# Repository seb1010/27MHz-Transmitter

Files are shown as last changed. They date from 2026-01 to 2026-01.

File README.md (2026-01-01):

# 27MHz-Transmitter
27.12MHz wiresless transmitter

## Basic flow
* There is a external oscillator that wakes up the MCU a few times every second (allowing MCU to sleep 99.9% of the time) if this is the Nth time the MCU has been woken up it sends a packet
* The MCU powers up the RF chain
* The MCU reads from the sensors then puts this information into a packet
* This packet has ECC added with 255, 154 BCH code. There is an additional framing section added that is not protected by error correction
* The packet is sent out by toggling a gpio pin with 20us bit period
* This waveform is pulse shapped by low pass filters before being sent to the modulator
* The modulated waveform is sent out over the airwaves
* The MCU powers off the board and goes back to sleep

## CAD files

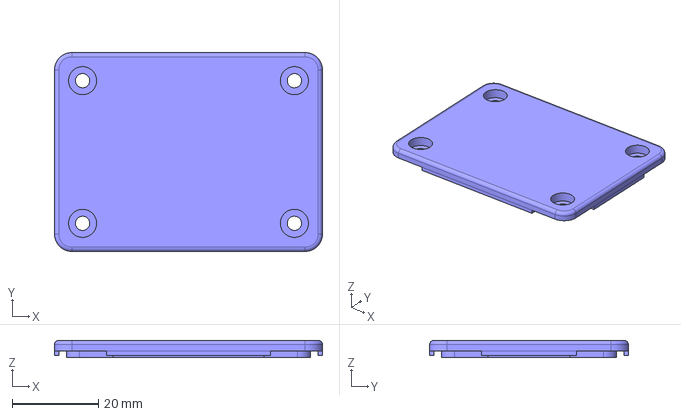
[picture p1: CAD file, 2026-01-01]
enclosure/27m_tx_sensor-lid_v2.step
62.0 x 46.0 x 4.00 mm

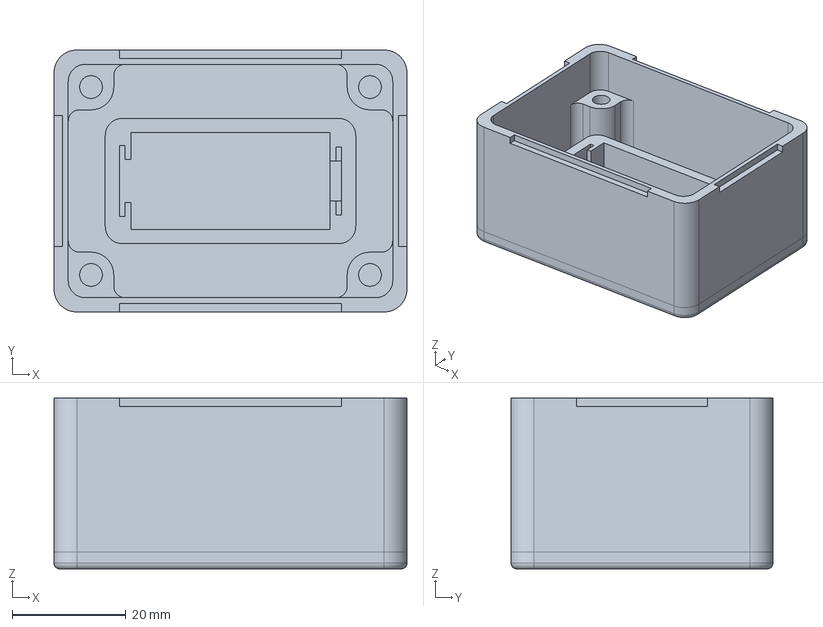
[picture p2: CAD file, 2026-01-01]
enclosure/27m_tx_sensor-Body_v2.step
62.0 x 46.0 x 30.0 mm

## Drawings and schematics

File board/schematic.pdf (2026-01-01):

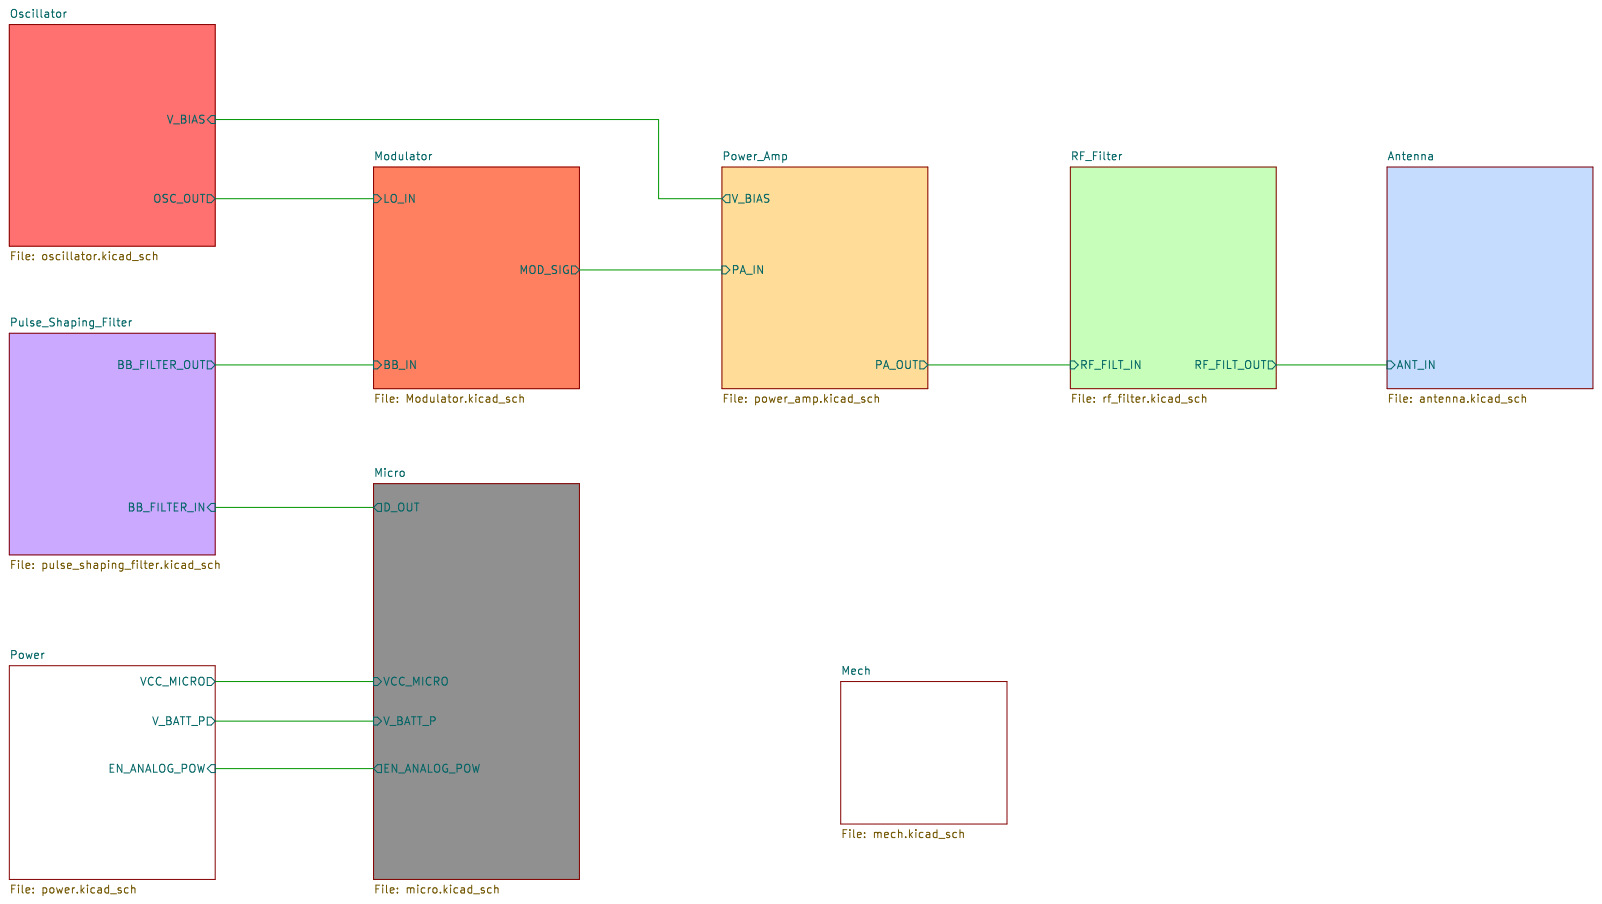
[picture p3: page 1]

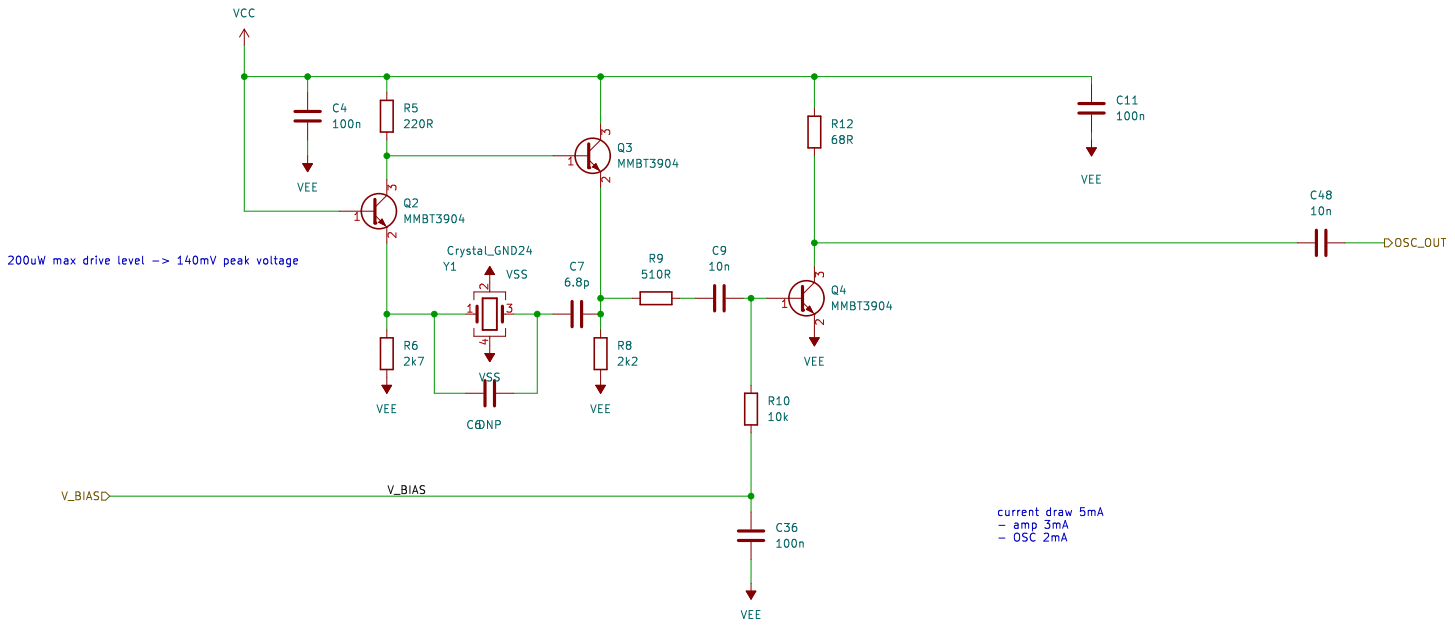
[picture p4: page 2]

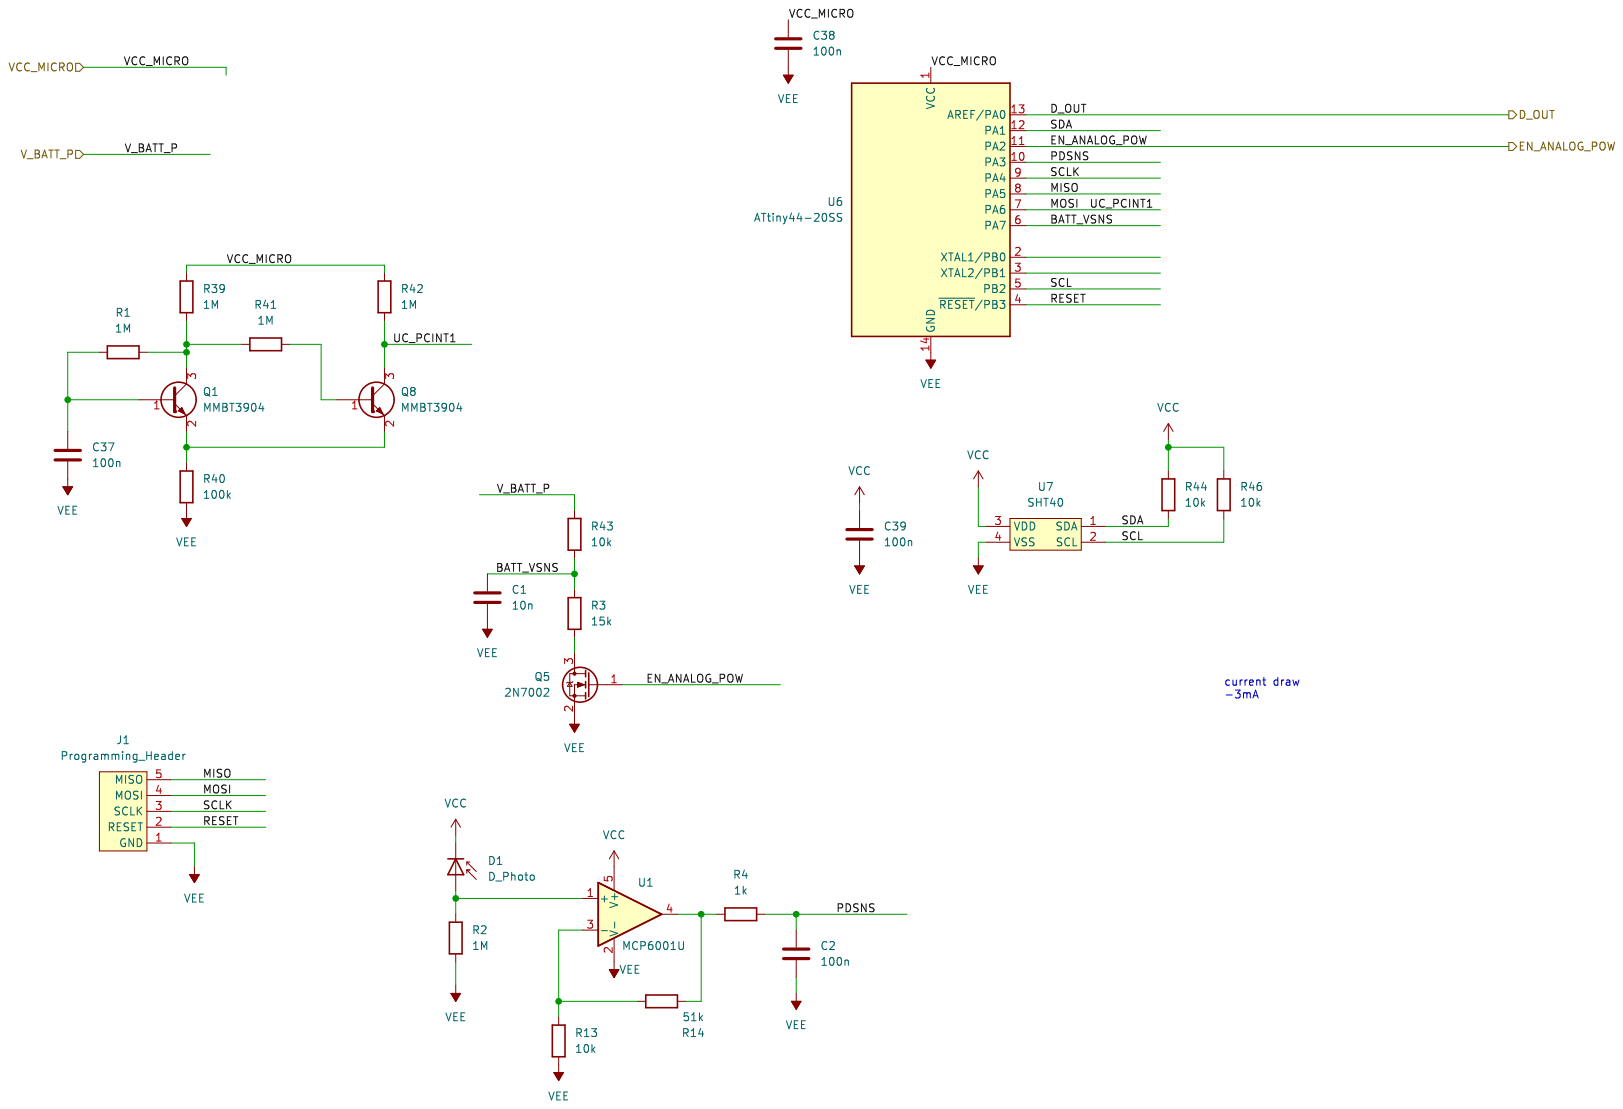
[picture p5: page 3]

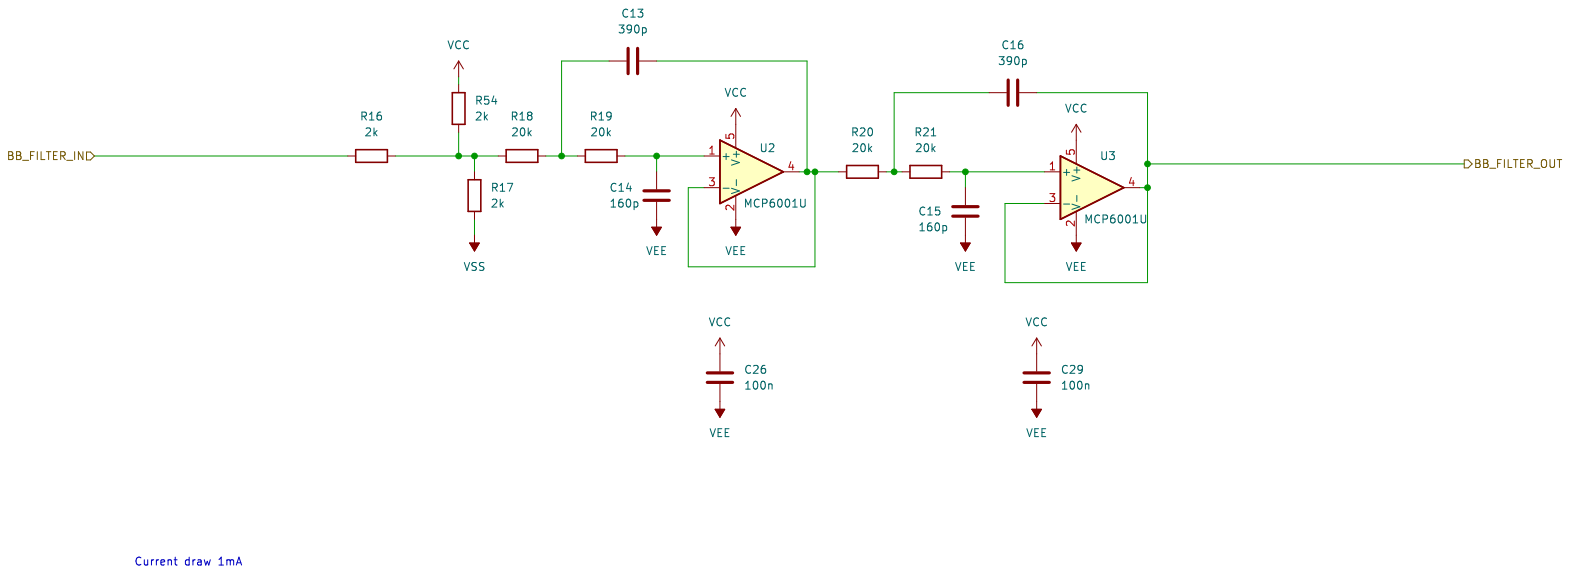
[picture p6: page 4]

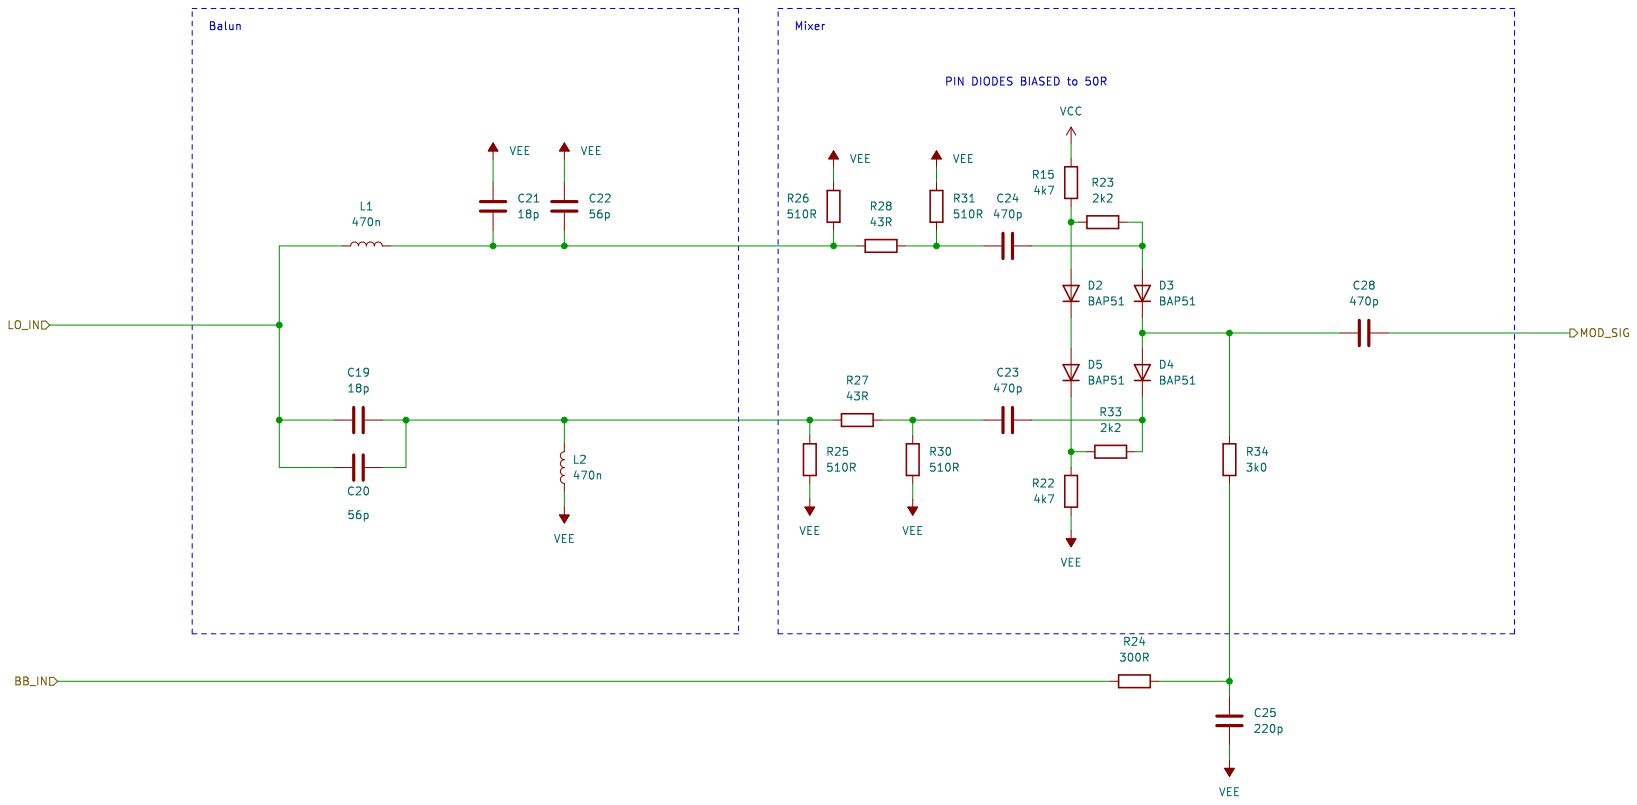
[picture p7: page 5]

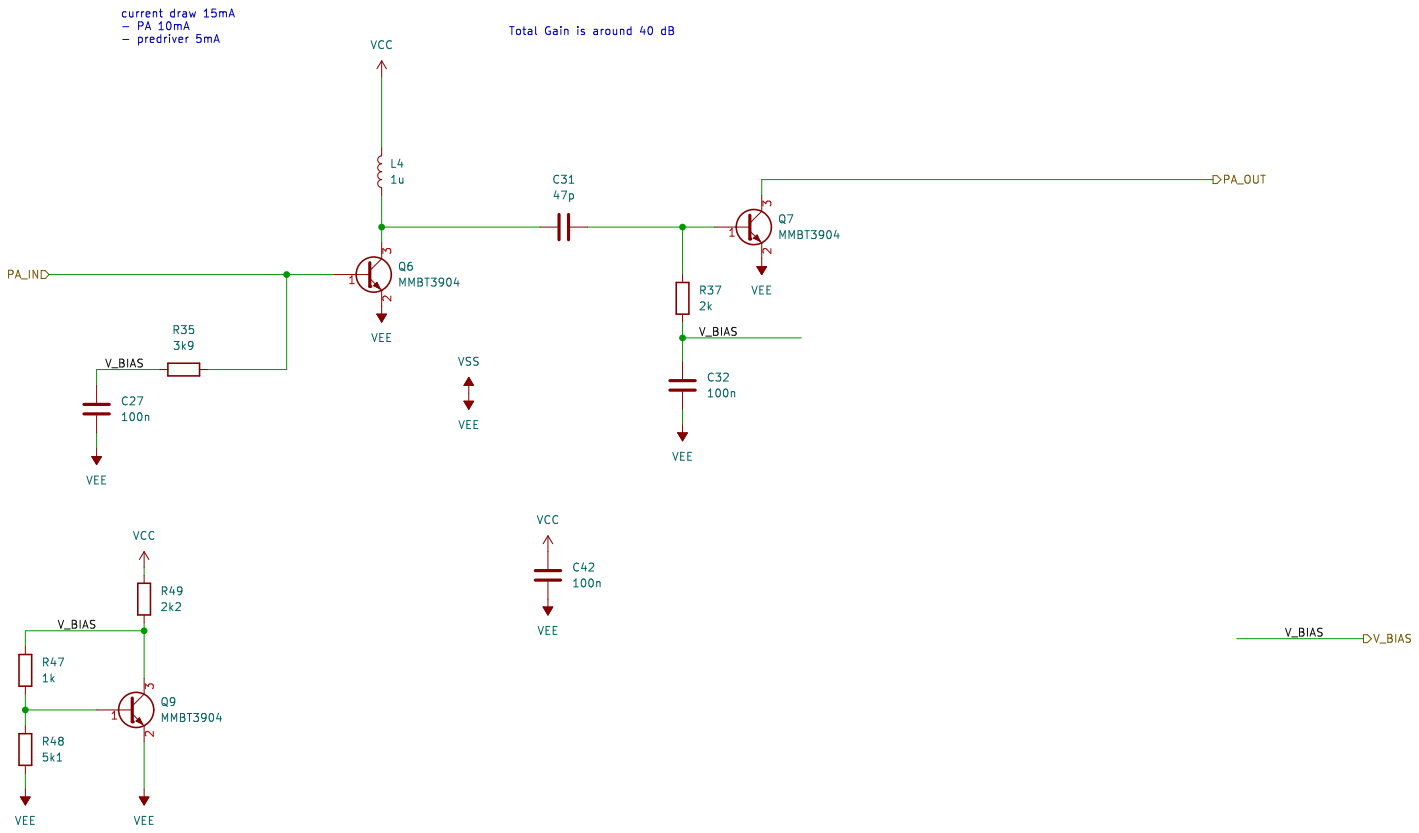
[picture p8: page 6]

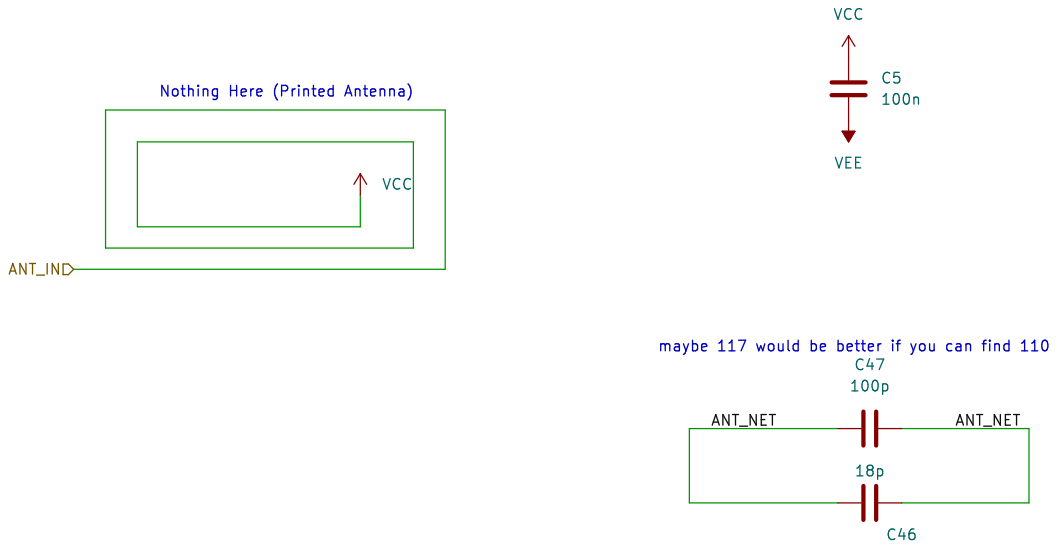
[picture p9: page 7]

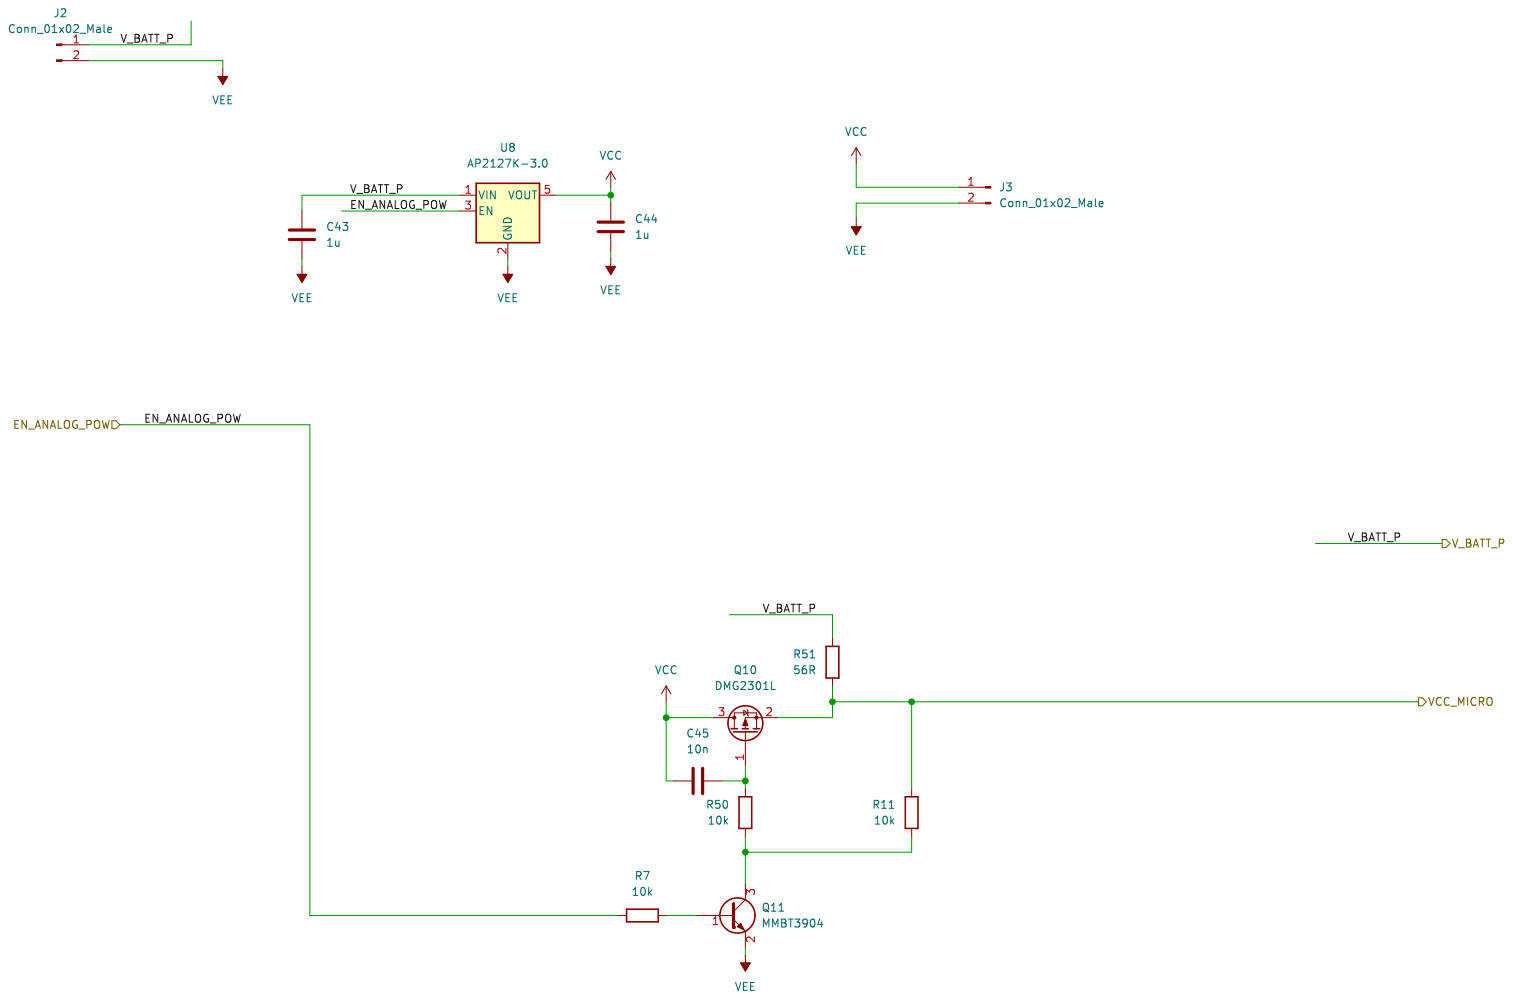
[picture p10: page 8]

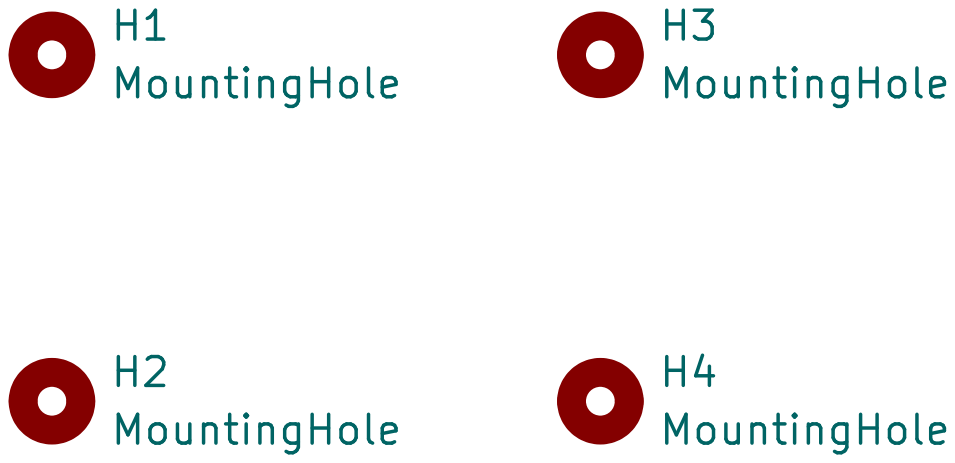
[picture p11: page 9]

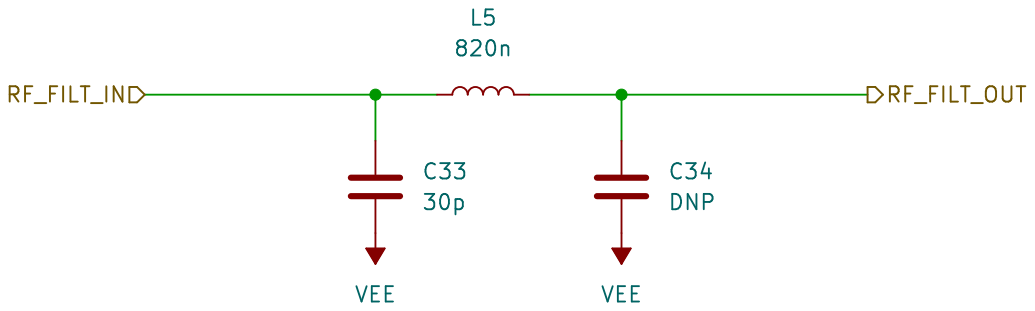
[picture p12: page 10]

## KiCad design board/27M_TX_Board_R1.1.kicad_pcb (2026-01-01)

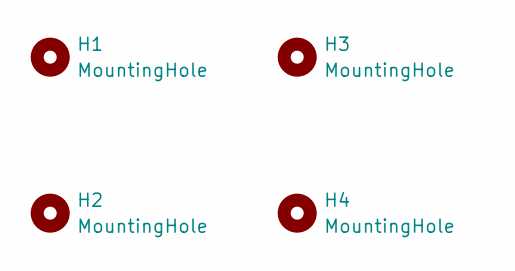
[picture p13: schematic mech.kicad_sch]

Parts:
H1, H2, H3, H4: MountingHole; m3_hole_no_copper

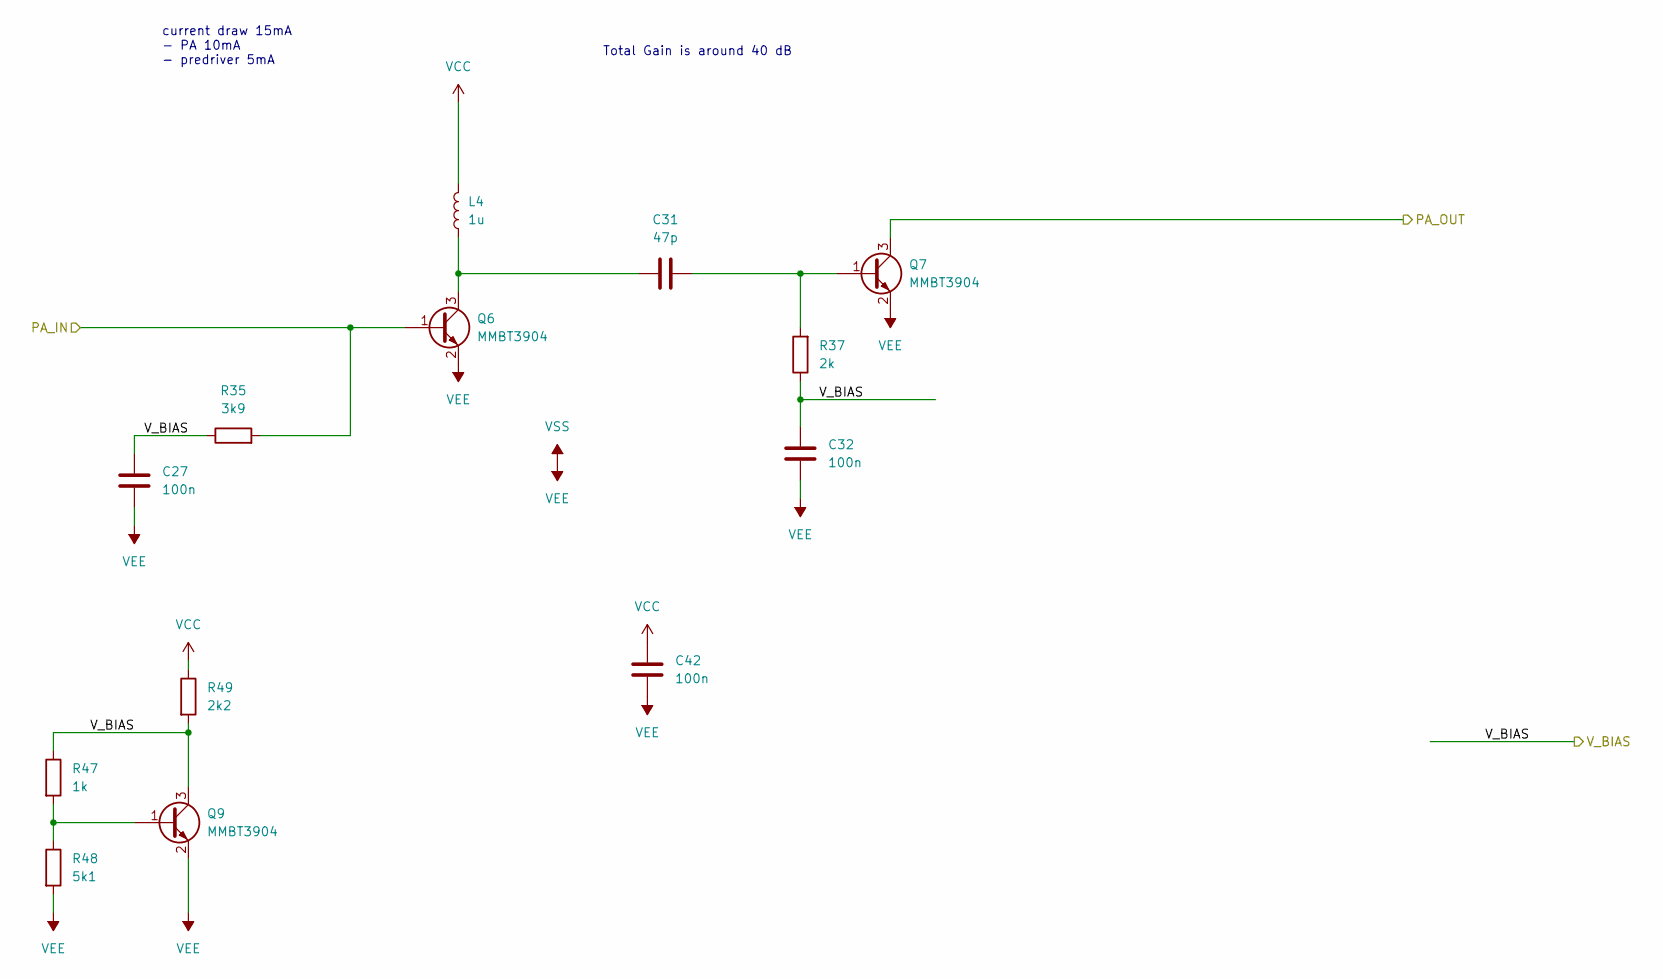
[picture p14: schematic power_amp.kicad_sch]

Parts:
C27, C32, C42: 100n; C_0603_1608Metric
C31: 47p; C_0603_1608Metric
L4: 1u; C_0805_2012Metric
Q6, Q7, Q9: MMBT3904; SOT-23
R35: 3k9; C_0603_1608Metric
R37: 2k; C_0603_1608Metric
R47: 1k; C_0603_1608Metric
R48: 5k1; C_0603_1608Metric
R49: 2k2; C_0603_1608Metric

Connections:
/Modulator/MOD_SIG: Q6.1 (B), R35.2; also elsewhere on the board
/Oscillator/V_BIAS: C27.1, C32.1, Q9.3 (C), R35.1, R37.1, R47.1, R49.2; also elsewhere on the board
/Power_Amp/PA_OUT: Q7.3 (C); also elsewhere on the board
unnamed: C31.1, L4.1, Q6.3 (C)
unnamed: C31.2, Q7.1 (B), R37.2
unnamed: Q9.1 (B), R47.2, R48.1
VCC: C42.1, L4.2, R49.1; also elsewhere on the board
VEE: C27.2, C32.2, C42.2, Q6.2 (E), Q7.2 (E), Q9.2 (E), R48.2; also elsewhere on the board

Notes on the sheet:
current draw 15mA - PA 10mA - predriver 5mA
Total Gain is around 40 dB

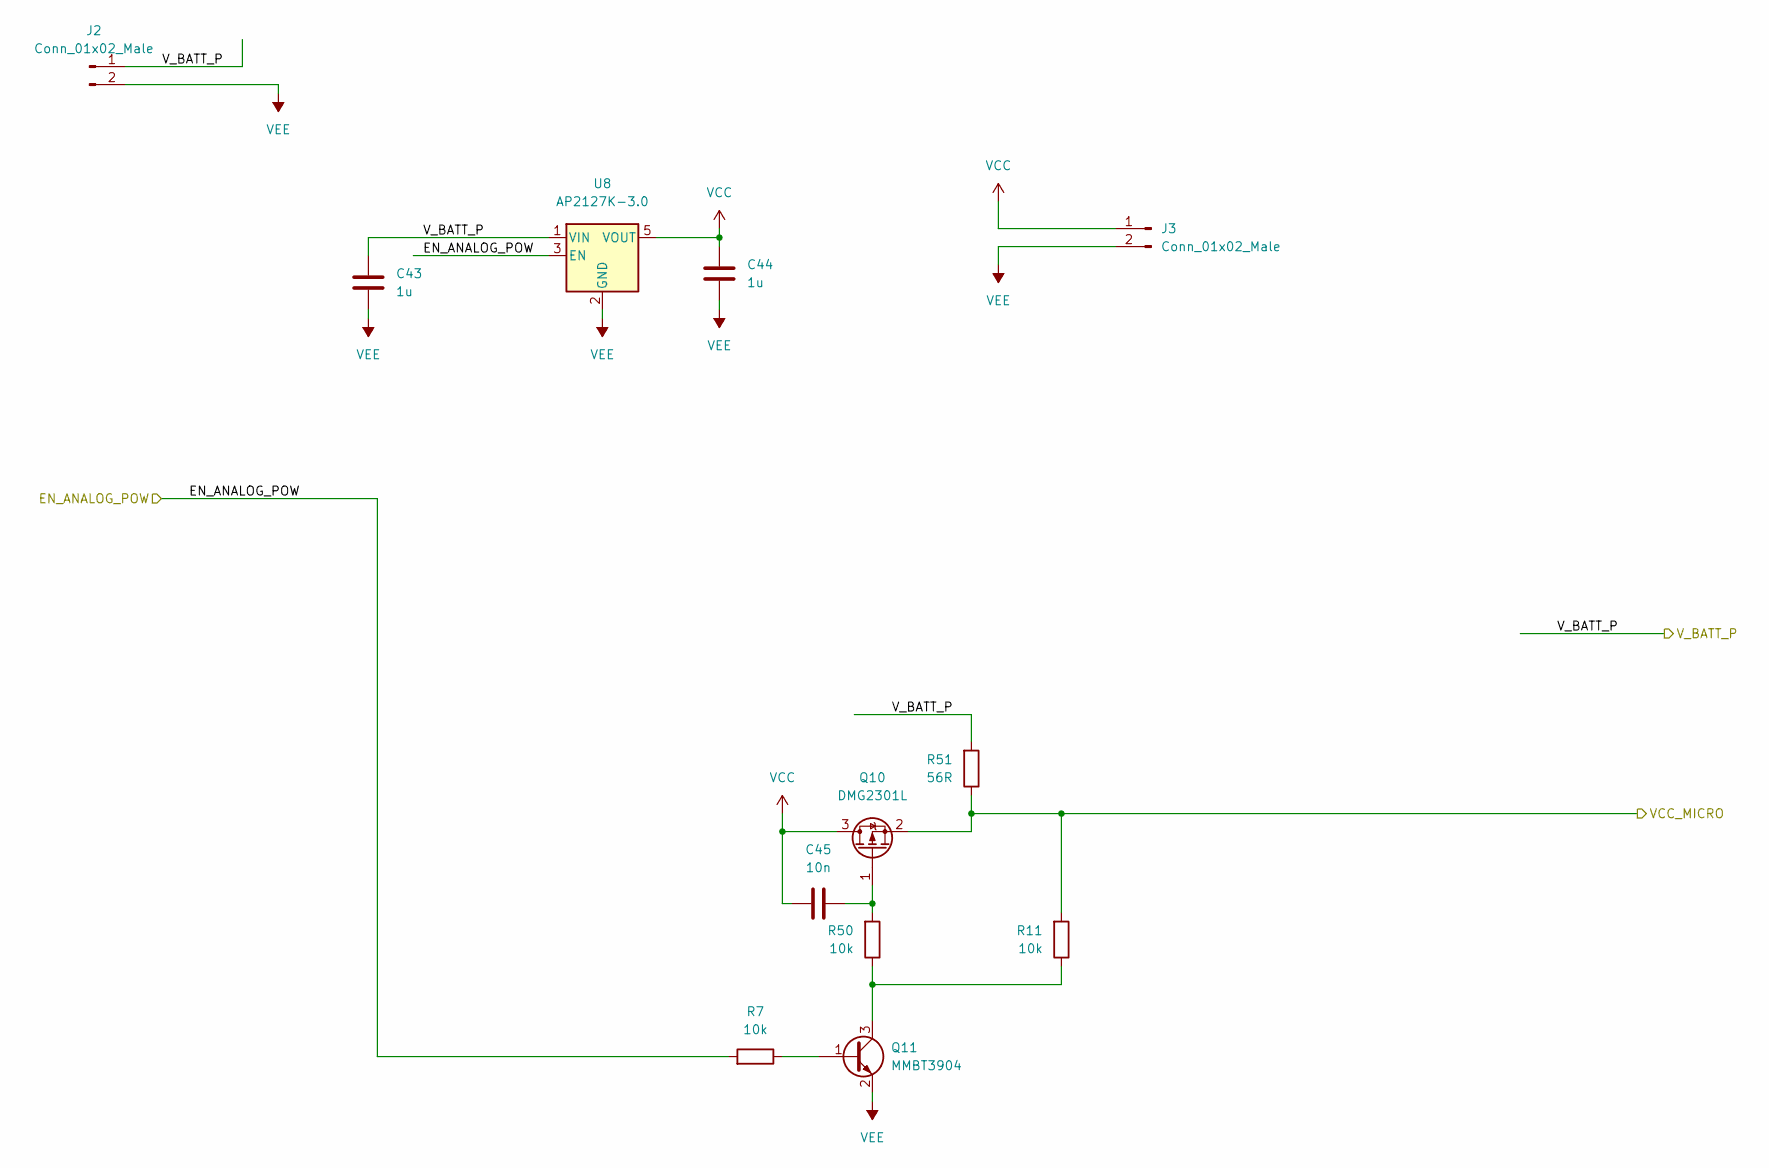
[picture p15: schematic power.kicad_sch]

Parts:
C43, C44: 1u; C_0603_1608Metric
C45: 10n; C_0603_1608Metric
J2, J3: Conn_01x02_Male; JST-ZH-2
Q10: DMG2301L; SOT-23
Q11: MMBT3904; SOT-23
R7, R11, R50: 10k; C_0603_1608Metric
R51: 56R; C_0603_1608Metric
U8: AP2127K-3.0; SOT-23-5

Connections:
/Micro/EN_ANALOG_POW: R7.2, U8.3 (EN); also elsewhere on the board
/Micro/VCC_MICRO: Q10.2 (S), R11.2, R51.1; also elsewhere on the board
/Micro/V_BATT_P: C43.1, J2.1, R51.2, U8.1 (VIN); also elsewhere on the board
unnamed: C45.2, Q10.1 (G), R50.2
unnamed: Q11.1 (B), R7.1
unnamed: Q11.3 (C), R11.1, R50.1
VCC: C44.1, C45.1, J3.1, Q10.3 (D), U8.5 (VOUT); also elsewhere on the board
VEE: C43.2, C44.2, J2.2, J3.2, Q11.2 (E), U8.2 (GND); also elsewhere on the board

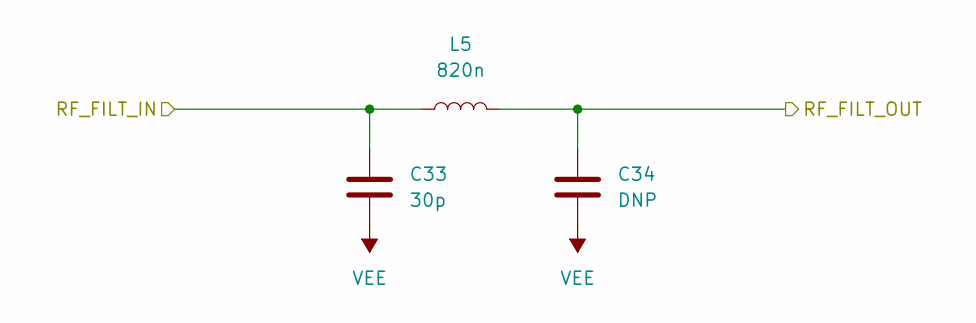
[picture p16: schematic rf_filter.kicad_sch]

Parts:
C33: 30p; C_0603_1608Metric
C34: DNP; C_0603_1608Metric
L5: 820n; C_0805_2012Metric

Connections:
/Power_Amp/PA_OUT: C33.1, L5.1; also elsewhere on the board
VCC: C34.1, L5.2; also elsewhere on the board
VEE: C33.2, C34.2; also elsewhere on the board

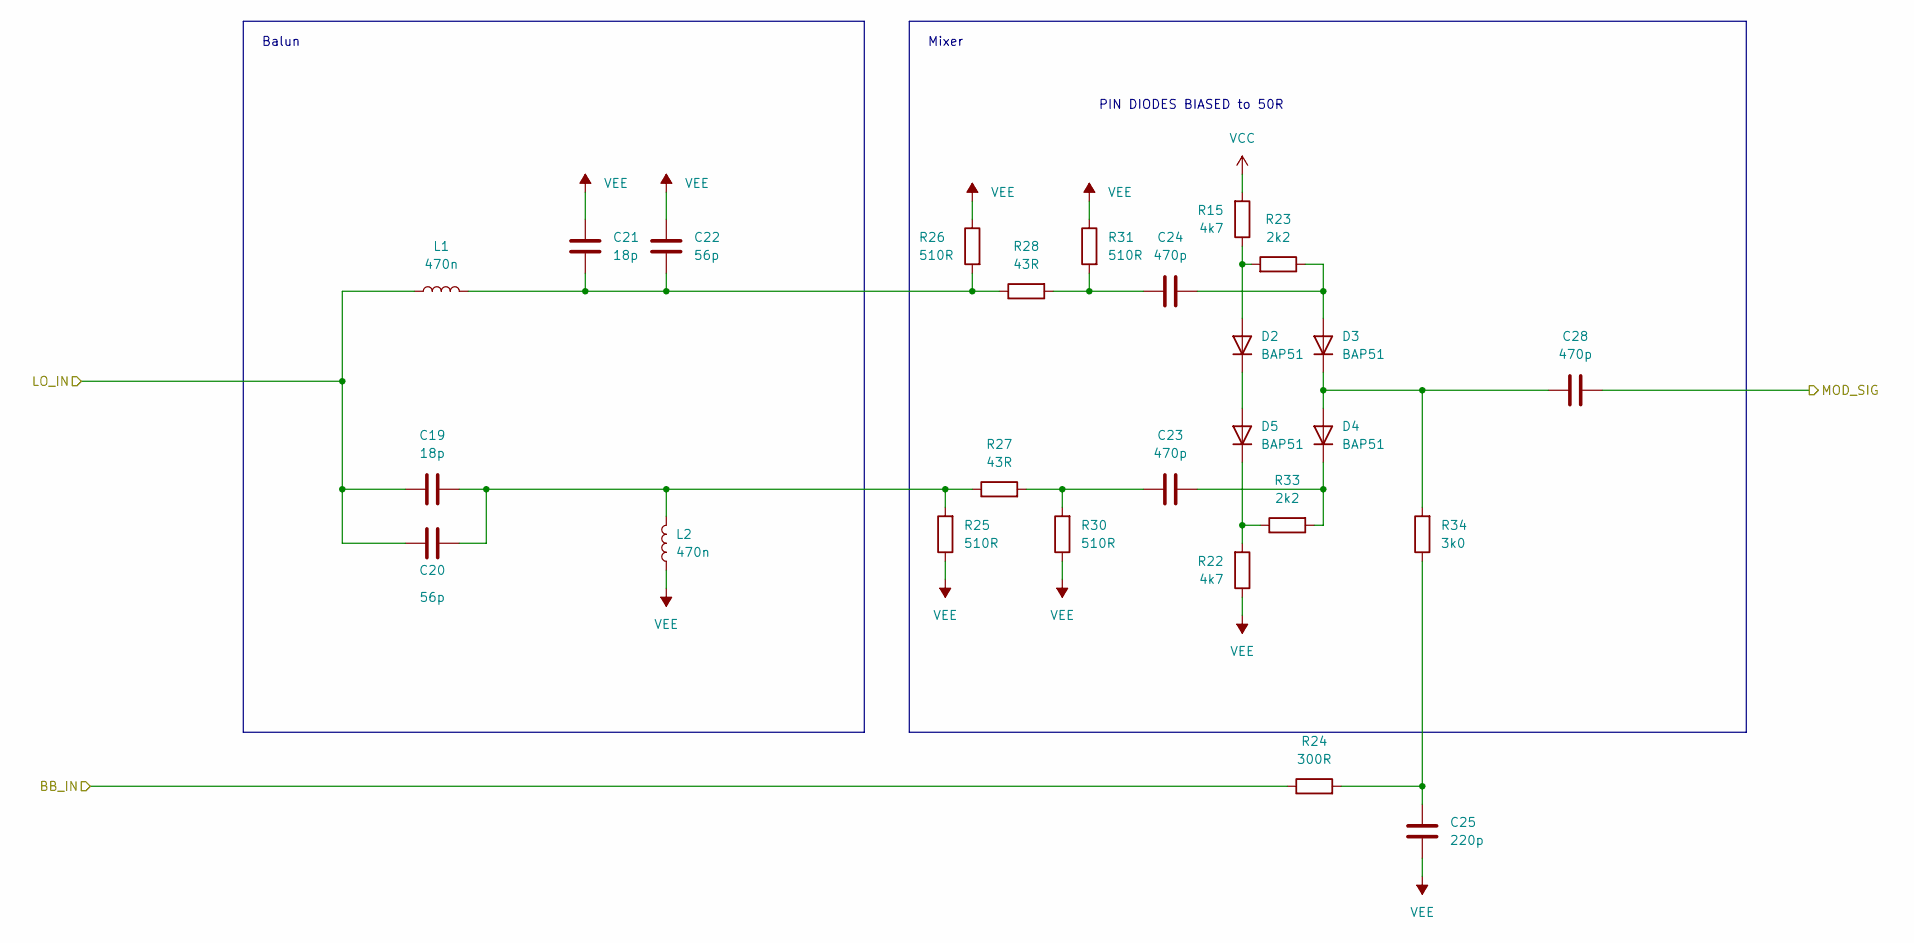
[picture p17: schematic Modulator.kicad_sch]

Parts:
C19, C21: 18p; C_0603_1608Metric
C20, C22: 56p; C_0603_1608Metric
C23, C24, C28: 470p; C_0603_1608Metric
C25: 220p; C_0603_1608Metric
D2, D3, D4, D5: BAP51; D_SOD-323
L1, L2: 470n; C_0805_2012Metric
R15, R22: 4k7; C_0603_1608Metric
R23, R33: 2k2; C_0603_1608Metric
R24: 300R; C_0603_1608Metric
R25, R26, R30, R31: 510R; C_0603_1608Metric
R27, R28: 43R; C_0603_1608Metric
R34: 3k0; C_0603_1608Metric

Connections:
/Modulator/BB_IN: R24.1; also elsewhere on the board
/Modulator/LO_IN: C19.1, C20.2, L1.1; also elsewhere on the board
/Modulator/MOD_SIG: C28.2; also elsewhere on the board
unnamed: C19.2, C20.1, L2.2, R25.2, R27.1
unnamed: C21.2, C22.2, L1.2, R26.2, R28.1
unnamed: C23.1, R27.2, R30.2
unnamed: C23.2, D4.1 (K), R33.2
unnamed: C24.1, R28.2, R31.2
unnamed: C24.2, D3.2 (A), R23.1
unnamed: C25.2, R24.2, R34.1
unnamed: C28.1, D3.1 (K), D4.2 (A), R34.2
unnamed: D2.1 (K), D5.2 (A)
unnamed: D2.2 (A), R15.1, R23.2
unnamed: D5.1 (K), R22.2, R33.1
VCC: R15.2; also elsewhere on the board
VEE: C21.1, C22.1, C25.1, L2.1, R22.1, R25.1, R26.1, R30.1, R31.1; also elsewhere on the board

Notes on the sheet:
Balun
Mixer
PIN DIODES BIASED to 50R

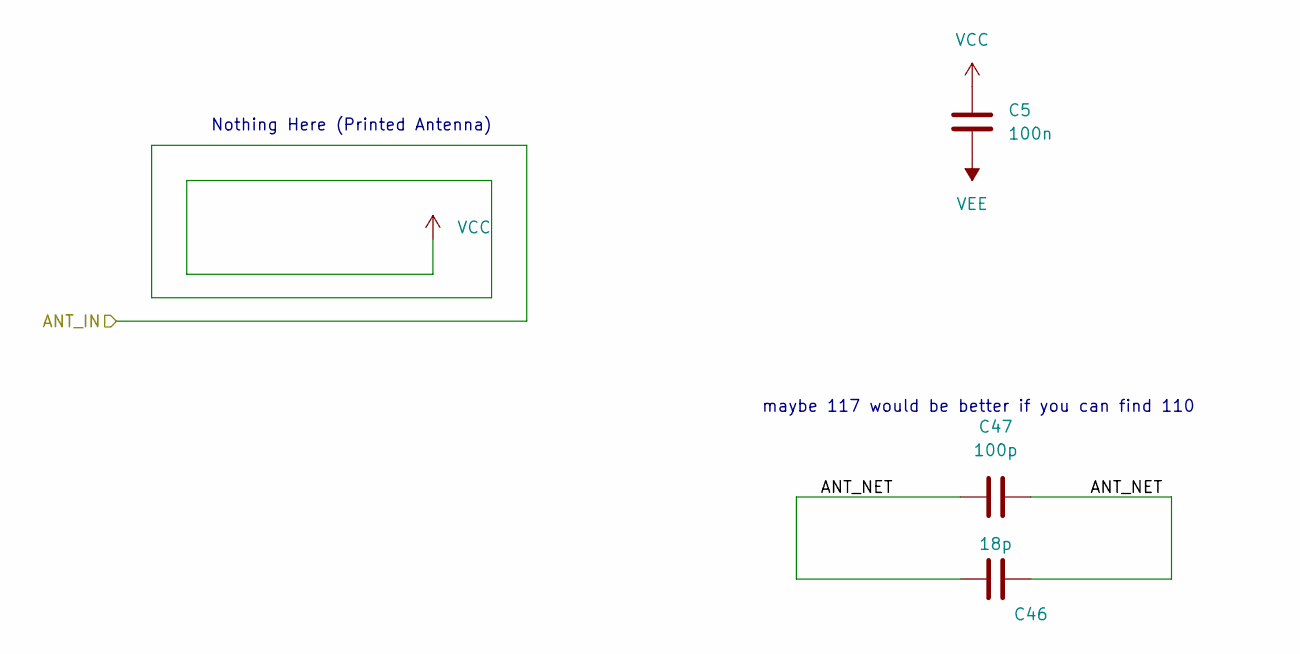
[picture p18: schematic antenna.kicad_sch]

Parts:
C5: 100n; C_0603_1608Metric
C46: 18p; C_0603_1608Metric
C47: 100p; C_0603_1608Metric

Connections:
/Antenna/ANT_NET: C46.1, C46.2, C47.1, C47.2
VCC: C5.1; also elsewhere on the board
VEE: C5.2; also elsewhere on the board

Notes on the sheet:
Nothing Here (Printed Antenna)
maybe 117 would be better if you can find 110

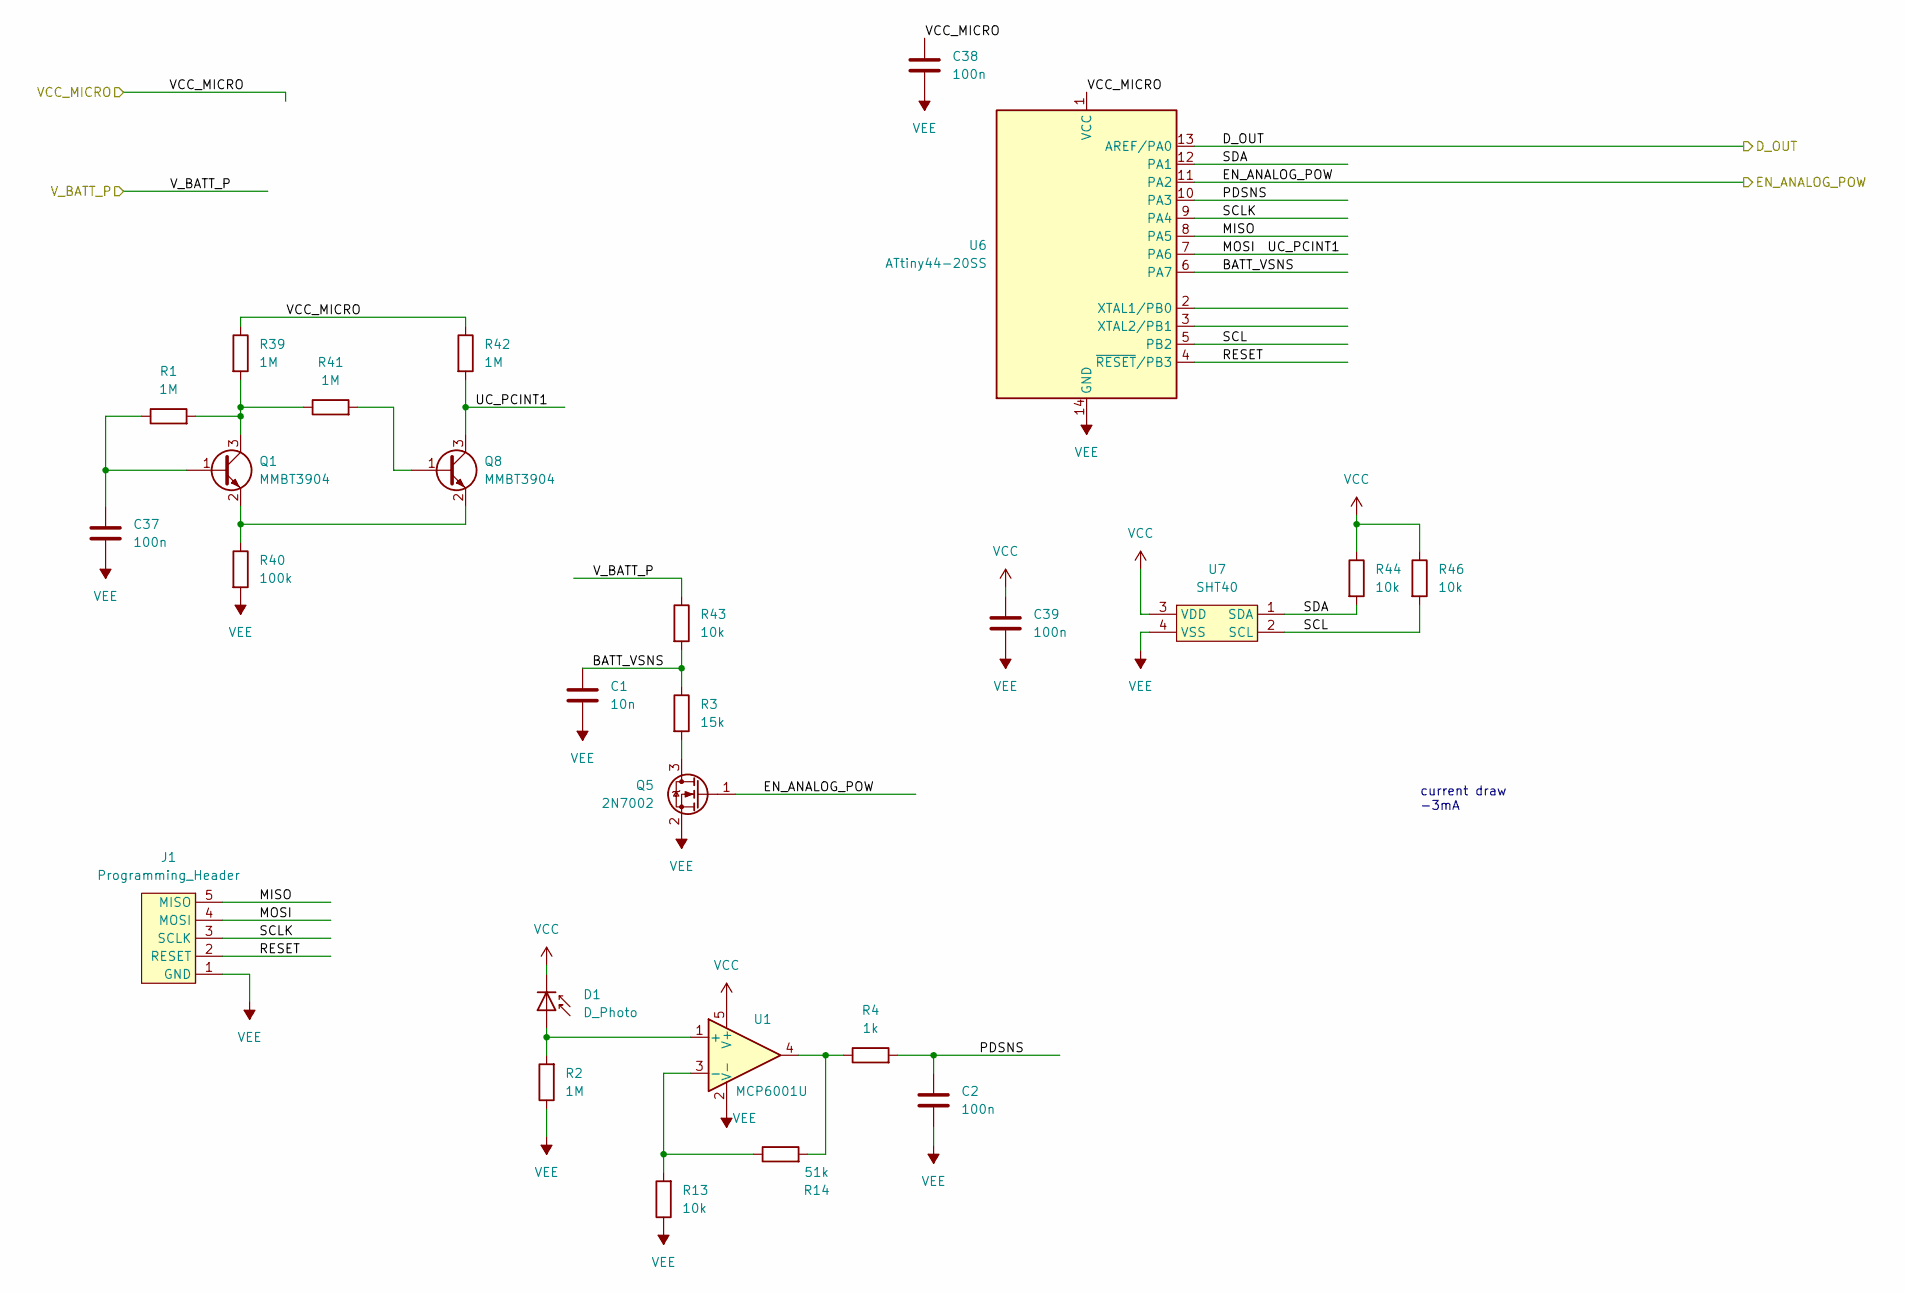
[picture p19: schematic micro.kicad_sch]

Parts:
C1: 10n; C_0603_1608Metric
C2, C37, C38, C39: 100n; C_0603_1608Metric
D1: D_Photo; LED_0805_2012Metric
J1: Programming_Header; JST-ZH-5
Q1, Q8: MMBT3904; SOT-23
Q5: 2N7002; SOT-23
R1, R2, R39, R41, R42: 1M; C_0603_1608Metric
R3: 15k; C_0603_1608Metric
R4: 1k; C_0603_1608Metric
R13, R43, R44, R46: 10k; C_0603_1608Metric
R14: 51k; C_0603_1608Metric
R40: 100k; C_0603_1608Metric
U1: MCP6001U; mcp6001
U6: ATtiny44-20SS; SOIC-14_3.9x8.7mm_P1.27mm
U7: SHT40

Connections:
/Micro/BATT_VSNS: C1.1, R3.1, R43.2, U6.6 (PA7)
/Micro/D_OUT: U6.13 (AREF/PA0); also elsewhere on the board
/Micro/EN_ANALOG_POW: Q5.1 (G), U6.11 (PA2); also elsewhere on the board
/Micro/MISO: J1.5 (MISO), U6.8 (PA5)
/Micro/MOSI: J1.4 (MOSI), Q8.3 (C), R42.2, U6.7 (PA6)
/Micro/PDSNS: C2.1, R4.2, U6.10 (PA3)
/Micro/RESET: J1.2 (RESET), U6.4 (~RESET/PB3)
/Micro/SCL: R46.2, U6.5 (PB2), U7.2 (SCL)
/Micro/SCLK: J1.3 (SCLK), U6.9 (PA4)
/Micro/SDA: R44.2, U6.12 (PA1), U7.1 (SDA)
/Micro/VCC_MICRO: C38.1, R39.1, R42.1, U6.1 (VCC); also elsewhere on the board
/Micro/V_BATT_P: R43.1; also elsewhere on the board
unnamed: C37.1, Q1.1 (B), R1.1
unnamed: D1.2 (A), R2.2, U1.1 (+)
unnamed: Q1.2 (E), Q8.2 (E), R40.1
unnamed: Q1.3 (C), R1.2, R39.2, R41.1
unnamed: Q5.3 (D), R3.2
unnamed: Q8.1 (B), R41.2
unnamed: R13.2, R14.1, U1.3 (-)
unnamed: R4.1, R14.2, U1.4
VCC: C39.1, D1.1 (K), R44.1, R46.1, U1.5 (V+), U7.3 (VDD); also elsewhere on the board
VEE: C1.2, C2.2, C37.2, C38.2, C39.2, J1.1 (GND), Q5.2 (S), R2.1, R13.1, R40.2, U1.2 (V-), U6.14 (GND), U7.4 (VSS); also elsewhere on the board

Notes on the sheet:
current draw -3mA

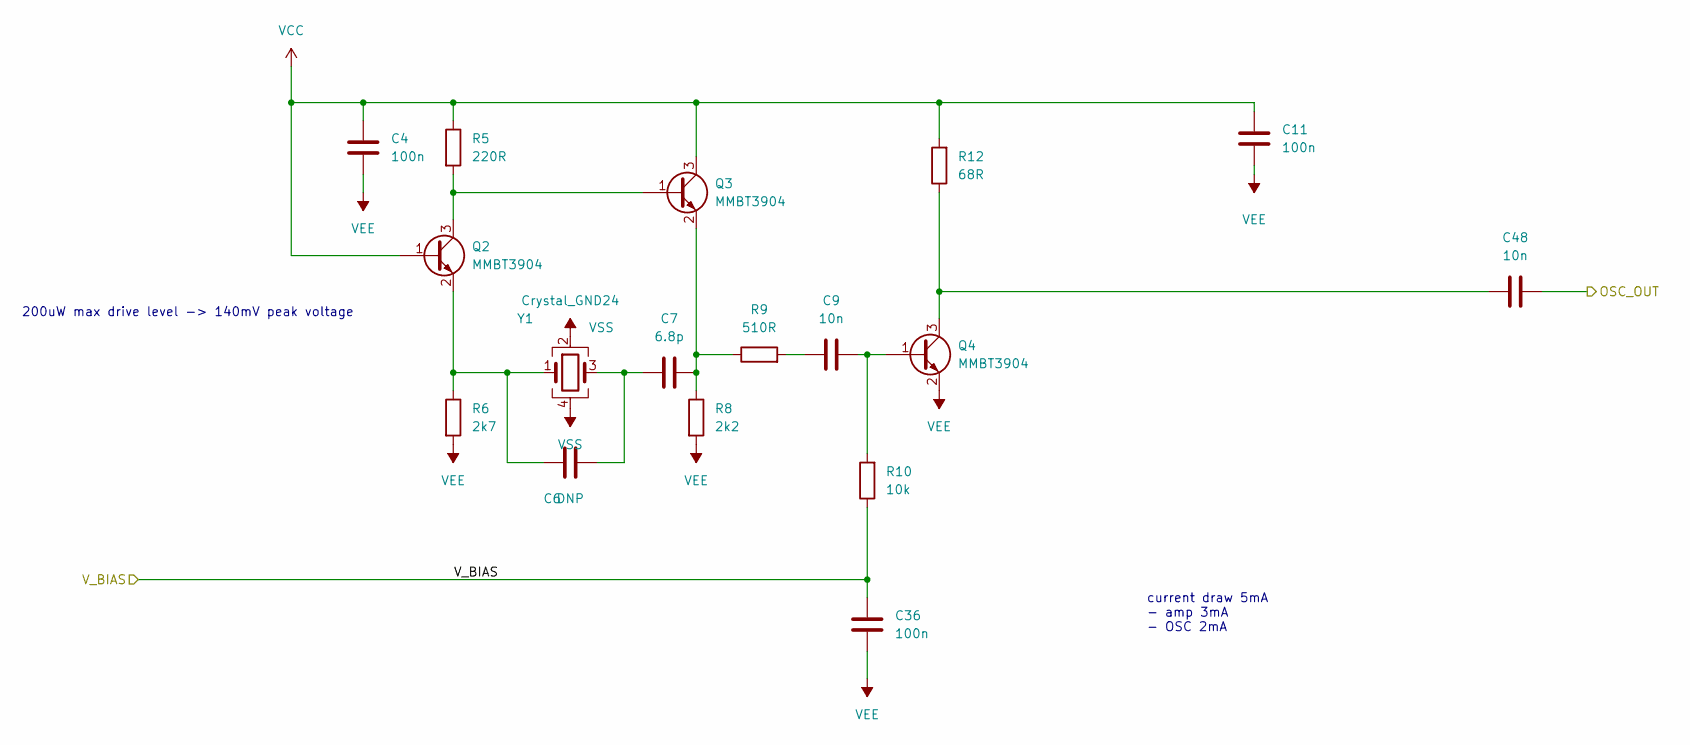
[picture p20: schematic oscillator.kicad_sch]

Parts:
C4, C11, C36: 100n; C_0603_1608Metric
C6: DNP; C_0603_1608Metric
C7: 6.8p; C_0603_1608Metric
C9, C48: 10n; C_0603_1608Metric
Q2, Q3, Q4: MMBT3904; SOT-23
R5: 220R; C_0603_1608Metric
R6: 2k7; C_0603_1608Metric
R8: 2k2; C_0603_1608Metric
R9: 510R; C_0603_1608Metric
R10: 10k; C_0603_1608Metric
R12: 68R; C_0603_1608Metric
Y1: Crystal_GND24; RH100

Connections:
/Modulator/LO_IN: C48.1; also elsewhere on the board
/Oscillator/V_BIAS: C36.1, R10.1; also elsewhere on the board
unnamed: C6.1, C7.2, Y1.3
unnamed: C6.2, Q2.2 (E), R6.1, Y1.1
unnamed: C7.1, Q3.2 (E), R8.1, R9.1
unnamed: C9.1, Q4.1 (B), R10.2
unnamed: C9.2, R9.2
unnamed: C48.2, Q4.3 (C), R12.1
unnamed: Q2.3 (C), Q3.1 (B), R5.2
VCC: C4.2, C11.2, Q2.1 (B), Q3.3 (C), R5.1, R12.2; also elsewhere on the board
VEE: C4.1, C11.1, C36.2, Q4.2 (E), R6.2, R8.2, Y1.2, Y1.4; also elsewhere on the board

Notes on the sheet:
current draw 5mA - amp 3mA - OSC 2mA
200uW max drive level -> 140mV peak voltage

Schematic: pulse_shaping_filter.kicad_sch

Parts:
C13, C16: 390p; C_0603_1608Metric
C14, C15: 160p; C_0603_1608Metric
C26, C29: 100n; C_0603_1608Metric
R16, R17, R54: 2k; C_0603_1608Metric
R18, R19, R20, R21: 20k; C_0603_1608Metric
U2, U3: MCP6001U; mcp6001

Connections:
/Micro/D_OUT: R16.1; also elsewhere on the board
/Modulator/BB_IN: C16.2, U3.3 (-), U3.4; also elsewhere on the board
unnamed: C13.1, R18.2, R19.1
unnamed: C13.2, R20.1, U2.3 (-), U2.4
unnamed: C14.1, R19.2, U2.1 (+)
unnamed: C15.1, R21.2, U3.1 (+)
unnamed: C16.1, R20.2, R21.1
unnamed: R16.2, R17.1, R18.1, R54.2
VCC: C26.1, C29.1, R54.1, U2.5 (V+), U3.5 (V+); also elsewhere on the board
VEE: C14.2, C15.2, C26.2, C29.2, R17.2, U2.2 (V-), U3.2 (V-); also elsewhere on the board

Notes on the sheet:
Current draw 1mA

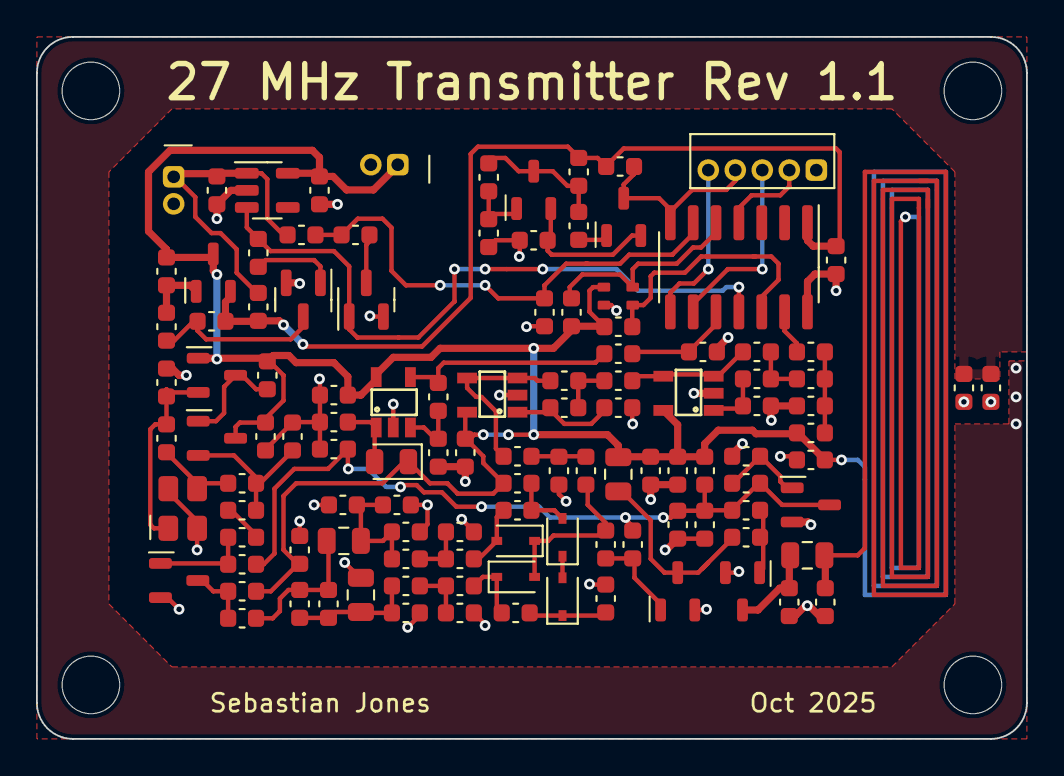
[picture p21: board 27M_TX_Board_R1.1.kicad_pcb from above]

Board: 2 copper layers, 55.0 x 39.0 mm, 119 parts (0 on the bottom side), 58 nets.

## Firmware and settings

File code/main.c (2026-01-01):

#include  <avr/io.h>
#include <util/delay_basic.h>
#include <avr/interrupt.h>
#include <avr/sleep.h>

#include "project.h"


uint8_t output_buffer[MAX_PACKET_LEN];
uint8_t input_offset = 0;

#include "drivers/sht4x.c"
#include "coding_and_framing.c"

void mock_sig(uint16_t);
void prbs_8();
extern void phy_send_frame(uint8_t*);
void load_packet(uint8_t*, uint16_t, uint16_t, uint16_t, uint16_t, uint16_t);
void adc_setup();
uint16_t read_adc(uint8_t);

extern void debug_uart_send_byte(uint8_t);

EMPTY_INTERRUPT(PCINT0_vect);

int main () {
  DDRB = (1 << DDB0) | (1 << DDB1) | (1 << DDB2);
  DDRA = (1 << UART_TX) | (1 << EN_POW);
  PORTA = (1 << EN_POW) | (1 << MISO); // enabling pullup on miso
  DDRA |= (1 << 5); // for debug uart

  //debug uart
  DDRA |= (1 << 5);
  PORTA |= (1 << 5);


  PCMSK0 = (1 << PCINT6);
  GIMSK = (1 << PCIE0);

  adc_setup();

  uint16_t temp_code;
  uint16_t rh_code;
  uint16_t battery_counts;
  uint16_t light_counts;
  uint16_t j = 0;

  uint8_t frame_buffer[FRAME_LENGTH];
  uint8_t* data_buffer = add_framing(frame_buffer);

  //about 20 counts per second
  uint16_t sleep_count = 20 * 60;

/*
uint8_t i;
while(1){
  i2c_init();
  sht4x_read_temp_and_rh(&temp_code, &rh_code, 0x44);


debug_uart_send_byte((uint8_t)(temp_code >> 8));
debug_uart_send_byte((uint8_t)temp_code);
debug_uart_send_byte(0xff);

for(i=0;i<10;i++)
  _delay_loop_2(0xffff);

}
*/
//mock_sig(100);
//prbs_8();  

  while(1){

    PORTA &= ~(1 << UART_TX); // output pin low
    PORTA &= ~(1 << EN_POW); // turn off RF chain

    sleep_for_awhile(sleep_count);

    PORTA |= (1 << EN_POW); // turn on RF chain

    i2c_init();
    _delay_loop_2(0x0400); // wait for powerup to happen
    sht4x_read_temp_and_rh(&temp_code, &rh_code, 0x44);

//_delay_loop_2(0xffff);
    light_counts = read_adc(PD_ADC_CH);
    battery_counts = read_adc(BAT_ADC_CH);

    load_packet(data_buffer, temp_code, rh_code,
        battery_counts, light_counts, j); 
    phy_send_frame(frame_buffer);

    j++;
  }
  return 0;
}


uint16_t read_adc(uint8_t channel){
  uint16_t adc_reading;
  ADCSRA |= (1 << ADEN); // enable ADC
  channel &= 0x07;
  ADMUX = ADMUX & 0xf8 | channel; // set correct channel

  ADCSRA |= (1 << ADSC) | (1 << ADIF); // clear flag and start converion 
  while(!(ADCSRA & (1 << ADIF))); // wait for flag to come high
  adc_reading = ADC;

  ADCSRA &= ~(1 << ADEN); // disable ADC

  return adc_reading;
}

void adc_setup(){
  ADCSRA = (1 << ADPS2) | (1 << ADPS1) | (1 << ADPS0); // set prescaler
  DIDR0 = (1 << 7) | (1 << 3); // disable digital input on adc pins
}

void sleep_for_awhile(uint16_t sleep_count){
  uint16_t i = 0;
  MCUCR |= (1 << SM1);
  MCUCR &= ~(1 << SM0);
  sei();
  sleep_enable();
  while (i < sleep_count){
    sleep_cpu();
    i++;
  }
  sleep_disable();
  cli();
}

void load_packet(uint8_t* data_buffer,
                          uint16_t temp_code,
                          uint16_t rh_code,
                          uint16_t bat_code,
                          uint16_t pd_code,
                          uint16_t packet_number){
  uint8_t i;
  for(i=0;i<18; i++) // load lots of transistions for cdr
    data_buffer[i] = 0xaa;

  data_buffer[18] = 0x00; // device ID
  data_buffer[19] = 0x20;

  data_buffer[0] = (uint8_t)(packet_number >> 8);
  data_buffer[1] = (uint8_t)packet_number;
   

  data_buffer[4] = (uint8_t)(temp_code >> 8);
  data_buffer[5] = (uint8_t)temp_code;
  data_buffer[8] = (uint8_t)(rh_code >> 8);
  data_buffer[9] = (uint8_t)rh_code;

  data_buffer[10] = (uint8_t)(bat_code >> 8);
  data_buffer[11] = (uint8_t)bat_code;
  data_buffer[12] = (uint8_t)(pd_code >> 8);
  data_buffer[13] = (uint8_t)pd_code;

  encode_data(data_buffer);
}

void send_debug_frame(uint8_t* frame_buffer){
// clocked out frame that without proper timing
  uint8_t i;
  for(i=0;i<FRAME_LENGTH;i++){
    send_debug_byte(frame_buffer[i]);
  }
}

void send_debug_byte(uint8_t data){
  uint8_t i;

  DDRA |= (1 << 5);

  for(i=0;i<8;i++){
    if(!(data & 0x80))
      PORTA |= (1 << UART_TX);
    else
      PORTA &= ~(1 << UART_TX);

    PORTA |= (1 << 5);
    _delay_loop_2(0x0c);
    PORTA &= ~(1 << 5);
    _delay_loop_2(0x0c);
    data <<= 1;
  }
}

void mock_sig(uint16_t delay){
  uint16_t i;
  while(1){
    for(i=0; i<delay; i++)
      _delay_loop_1(0x01);
    PORTA ^= (1 << UART_TX);
  }
}

void prbs_8(){
  uint8_t poly, port, count, reg = 0x59;

  poly = (1 << 4) | (1 << 3) | (1 << 2) | (1 << 0);
  port = PORTA;
  asm volatile(
    "main_loop: \n\t"
      "lsl %[reg] \n\t"
      "brcc no_eor \n\t"
        "eor %[reg], %[poly] \n\t"
      "no_eor: \n\t"      

    "cbr %[port], (1 << %[tx_pin]) | (1 << 5) \n\t" // delete (1 << 5)
    "sbrc %[reg], 0 \n\t"
      "sbr %[port], (1 << %[tx_pin]) \n\t"
    "out %[port_addr], %[port] \n\t"

    "ldi %[cnt], 50 \n\t"
    "stupid_loop: \n\t"
    "dec %[cnt] \n\t"
    "brne stupid_loop \n\t"

    "rjmp main_loop \n\t"
  :
  : [poly] "r" (poly),
    [port] "a" (port),
    [reg] "a" (reg),
    [cnt] "r" (count),
    [tx_pin] "M" (UART_TX),
    [port_addr] "M" (_SFR_IO_ADDR(PORTA))
  );

}

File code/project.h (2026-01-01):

#define CLK_FREQ 8000000UL
#define UART_TX 0
#define F_CPU CLK_FREQ
#define EN_POW 2

#define MOSI 0x06
#define MISO 0x05

#define FRAME_LENGTH 38
#define DATA_LENGTH FRAME_LENGTH - 6

#define MAX_PACKET_LEN 2

#define BAT_ADC_CH 7
#define PD_ADC_CH 3


#define DDR_SCL DDRB
#define DDR_SDA DDRA
#define PORT_SCL PORTB
#define PORT_SDA PORTA
#define PIN_SCL PINB
#define PIN_SDA PINA
#define SCL 0x02
#define SDA 0x01
